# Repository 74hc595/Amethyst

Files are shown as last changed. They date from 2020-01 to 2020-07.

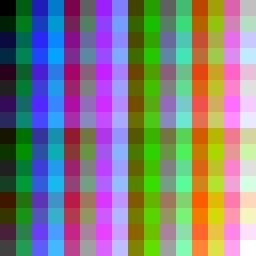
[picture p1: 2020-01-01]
palettes/8bit-preview.png

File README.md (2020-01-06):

# The Amethyst Colour Video System

https://www.youtube.com/watch?v=6GKgxBEGH1M

The Amethyst is a retro-styled "home computer" built around an Atmel ATmega1284 microcontroller.
It features composite (NTSC) video output with both high-color and high-resolution modes, mono
audio output, and a full-travel mechanical keyboard. It includes a full-featured implementation
of the powerful Forth programming language, with graphics and sound commands, debugger, and
screen editor. A single USB Type-B cable provides 5V power as well as serial communication with
a PC. Amethyst is compatible with the Optiboot (Arduino) bootloader, and new firmware may be
uploaded to it without a specialized programming device.

## Full specifications

- ATmega1284 microcontroller (8-bit) running at 14.318 MHz
- 16KB internal memory (16352 bytes available for applications)
- 4KB nonvolatile EEPROM memory
- Mechanical keyboard with Cherry MX keyswitches
- NTSC color and monochrome composite video output:

    - 256-color, 16-color, and 4-color bitmap graphics at resolutions up to 160x200 pixels
    - Monochrome bitmap graphics at resolutions up to 640x200 pixels
    - 40x25 and 80x25 monochrome text modes
    - 40x25 color text mode
    - 40x25 color tiled graphics modes
    
- Single-channel audio output (pulse wave or PWM)
- USB serial communication at speeds up to 57600 baud
- Four SPI expansion ports for peripherals, controllers, and storage devices
- Only 6 chips (ATmega1284, FT320X, 2x 74HC157, 2x 74HC166)

**TODO 1/5/20: add more detailed docs, instructions, and BOM**

## About

Amethyst is a hobby project and is not currently available for purchase in kit or built form.

Copyright 2019 Matt Sarnoff.

https://twitter.com/txsector

http://msarnoff.org

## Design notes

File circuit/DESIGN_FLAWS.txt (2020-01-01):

The Amethyst's design isn't perfect. It has several shortcomings. These
are some aspects of the design that could be improved:

The luminance levels of the video signal are dependent on the supply voltage.
Fluctuations and noise on the 5V supply can manifest as flickering changes of
brightness in the image. This is exacerbated by the fact that the Amethyst has no onboard voltage regulator; it's entirely dependent on the 5V USB supply
voltage.

I did try to run the system at 3.3V using the 3V3 output of the FTDI chip.
Technically, at 14.318 MHz, you're running the AVR outside its "safe operating
area." (See Figure 29-1 in the ATmega1284 datasheet.) Most of the time the
system would work fine, but writing to the internal EEPROM would cause the CPU
to lock up or restart. (It is documented in several threads on the avrfreaks
forums that EEPROM tends to fail when an AVR is overclocked.) However, this
could have also been due to excessive current draw from the FT230X/FT231X's
3.3V regulator, which is only rated to deliver 50 mA. It's possible that
everything might work fine using a dedicated 3.3V LDO.

No fuse or reverse voltage protection on VUSB. Needs better filtering too,
probably.

Analog video and audio output stages are garbage. My focus was on minimizing
part count instead of picture quality. I'm sure there's a lot of room for
improvement here but I'm not much of an analog guy.

No PAL support. I don't think artifact color works with PAL anyway. Your modern
TV or capture device can probably decode NTSC, though.

Derive the maximum video signal amplitude from the AVR's 2.56V/1.1V analog
voltage reference at the AREF pin. Along with some 1% resistors, this might
eliminate the need for the two trimpots VR1 and VR2.

The ortholinear keyboard layout and lack of a spacebar take a while to get
used to. This was done to minimize board real estate. Sorry if it's not your
thing.

A major drawback: the video signal is generated in software. The AVR has
no DMA, which means the CPU needs to be stolen away to bitbang the image out
to the shift registers during the active video portion of the frame. This only
leaves about 25% of each frame for updating your program's logic. If you
wanted to get crazy, you could probably build a dual-processor system. You
could probably even have two AVRs sharing access to an external SRAM chip. You
could use a smaller AVR as a 6845 CRT controller--it would only be responsible
for VRAM address generation, and wouldn't need to be connected to the data
lines. Or you could use another '1284 as a video coprocessor to accelerate
blitting and line drawing operations.

The biggest drawback: the AVR can't run native code from SRAM. If you don't
want to use the Forth bytecode interpreter, loading a new native application
requires reprogramming the flash memory, which only has a finite number of
write cycles. An Arm would be better suited, but then (a) it wouldn't be
"8-bit," and (b) it wouldn't be constructible on a breadboard. (Rest in peace,
LPC1114FN28.)

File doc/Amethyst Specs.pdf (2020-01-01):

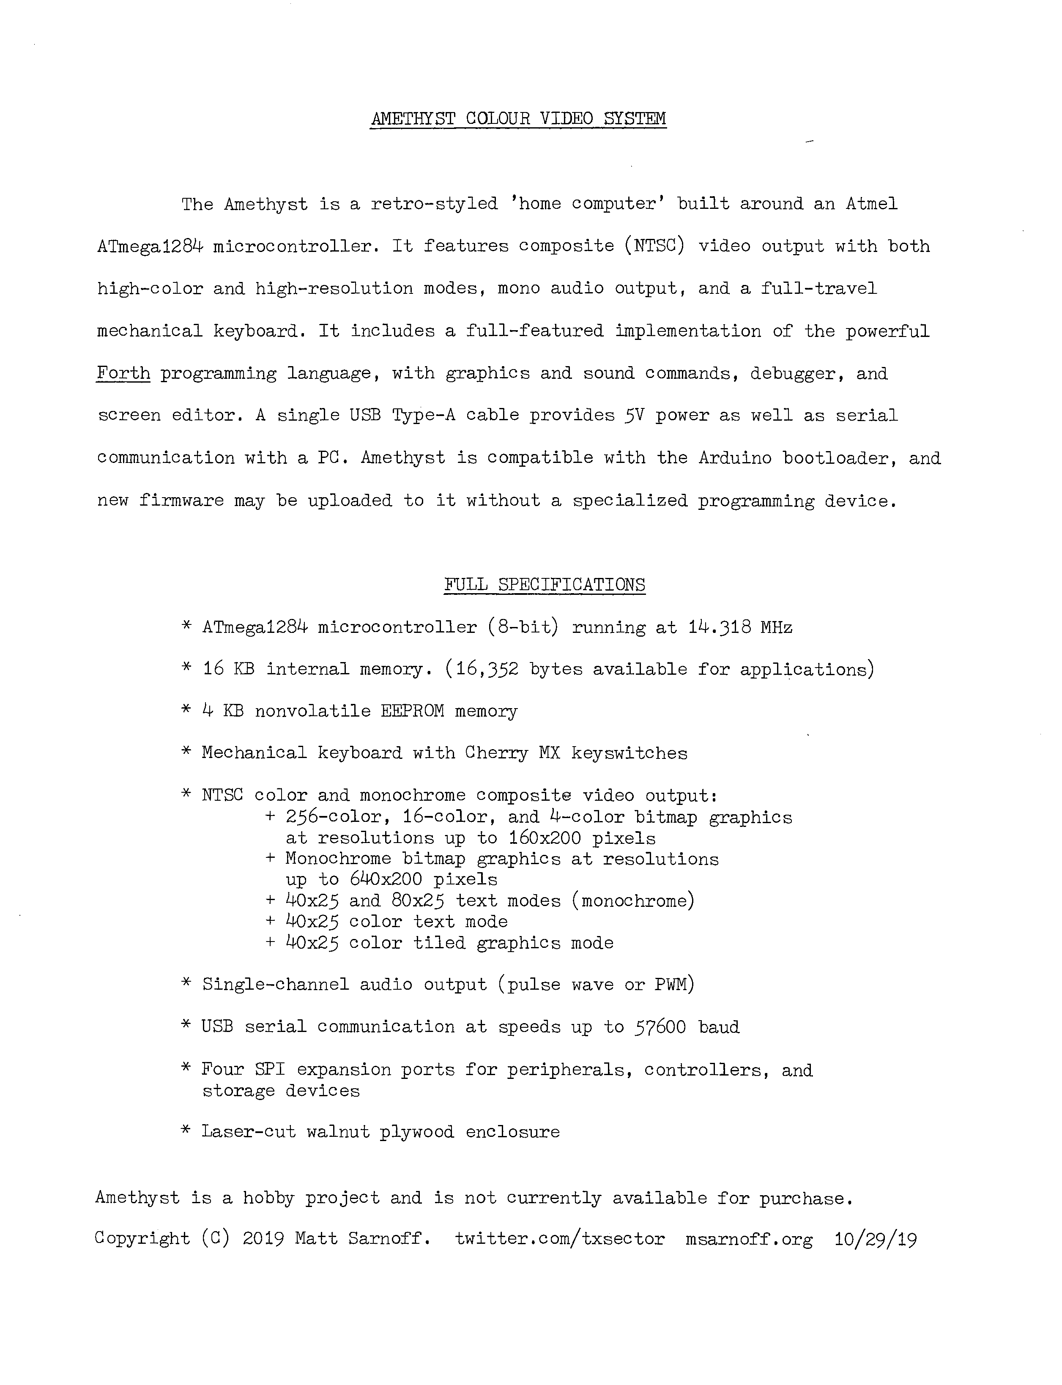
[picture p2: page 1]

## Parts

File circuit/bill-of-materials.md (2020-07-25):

## Amethyst Bill of Materials

| Reference | Qty | Description | Vendor link |
| --- | --- | --- | --- |
| C1-C2 | 2 | Capacitor, MLCC, 0603, 18pF, 50V, NPO, 5% | [Mouser](https://www.mouser.com/ProductDetail/603-CC603JRNPO9BN180) |
| C3-C5, C7-C11, C14-C16 | 10  | Capacitor, MLCC, 0603, 0.1uF, 10V, X7R, 5% | [Mouser](https://www.mouser.com/ProductDetail/77-VJ0603Y104JXQCBC) |
| C6 | 1 | Capacitor, electrolytic, through-hole, 10uF, 25V | Generic [(Amazon)](https://www.amazon.com/REXQualis-Electrolytic-Capacitor-Assortment-0-1uF-1000uF/dp/B081PT78Y5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) |
| C12-C13 | 2 | Capacitor, MLCC, 0603, 47pF, 100V, C0G, 5% | [Mouser](https://www.mouser.com/ProductDetail/KEMET/C0603C470J1GACTU?qs=sGAEpiMZZMvsSlwiRhF8qnEcMcxHm24QR9VWEEhdETo%3D) |
| D1-D47 | 47  | Diode, SMD, BAS16HT1G | [Mouser](https://www.mouser.com/ProductDetail/863-BAS16HT1G) |
| J1 | 1 | Connector, USB-B, right-angle, through-hole | [Jameco](https://www.jameco.com/shop/ProductDisplay?catalogId=10001&langId=-1&storeId=10001&productId=2096245) |
| J2 | 1 | Pin header, 0.1" pitch, straight, through hole, 2x3 | Generic [(Amazon)](https://www.amazon.com/Frienda-Break-Away-Connector-Compatible-Raspberry/dp/B083DYVWDN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) |
| J3 | 1 | Connector, RCA, female, right-angle, through-hole, yellow | [Jameco](https://www.jameco.com/z/KY-006-1-Y--Connector-RCA-Female-2-Position-Right-Angle-Thru-Hole-2-Terminal_220564.html) |
| J4 | 1 | Connector, RCA, female, right-angle, through-hole, white  | [Jameco](https://www.jameco.com/z/KY-006-1-Y--Connector-RCA-Female-2-Position-Right-Angle-Thru-Hole-2-Terminal_220564.html) |
| J5-J6 | 2 | Pin socket, 0.1" pitch, right-angle, through-hole, 1x6 | Generic [(Amazon)](https://www.amazon.com/Right-Female-Header-2-54mm-Connector/dp/B00R1M3JRQ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) |
| J7 | 1 | Pin socket, 0.1" pitch, right-angle, through-hole, 1x4 | Generic [(Amazon)](https://www.amazon.com/Right-Female-Header-2-54mm-Connector/dp/B00R1M3JRQ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) |
| J8-J9 | 2 | Connector, RJ-11, right-angle, through-hole, 6P6C | [Amazon](https://www.amazon.com/gp/product/B00LUT5VA4/ref=ppx_yo_dt_b_search_asin_title?ie=UTF8&psc=1) |
| K1-K47 | 47  | Keyswitch, Cherry MX, PCB mount (any color) | [MechanicalKeyboards.com](https://mechanicalkeyboards.com/shop/index.php?l=product_detail&p=1027) |
| (K1-K47) | 1 | DSA "Beyond" keycap set | [PimpMyKeyboard.com](https://pimpmykeyboard.com/dsa-beyond-keyset-sublimated/) |
| LED1 | 1 | LED, SMD, 1206 (any color) | Generic [(Amazon)](https://www.amazon.com/Assorted-Lighting-Electronics-Components-Emitting/dp/B01CUGAFEC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) |
| R1 | 1 | Resistor, SMD, 0603, 10k ohm, 100 mW, 5% | [Mouser](https://www.mouser.com/ProductDetail/Yageo/RC0603JR-0710KL?qs=ksOUTF%2FWcd8D6T22BJkQ7g%3D%3D) |
| R2 | 1 | Resistor, SMD, 0603, 1k ohm, 100 mW, 5% | [Mouser](https://www.mouser.com/ProductDetail/Yageo/RC0603JR-071KL?qs=%2F9ZTgpVJnN7bctK4R%2FDEoA%3D%3D) |
| R3-R4 | 2 | Resistor, SMD, 0603, 27 ohm, 100 mW, 1% | [Mouser](https://www.mouser.com/ProductDetail/Yageo/RC0603FR-0727RL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) |
| R5 | 1 | Resistor, SMD, 1206, 1.5k ohm*, 1/4 W, 1% | [Mouser](https://www.mouser.com/ProductDetail/Yageo/RT1206FRE071K5L?qs=8cPjvKtxWv7kOFMaeXZkoQ%3D%3D) |
| SW1 | 1 | Push switch, FSMSM | [Mouser](https://www.mouser.com/ProductDetail/TE-Connectivity-Alcoswitch/FSMSM?qs=UhRTNahLC3yPLf3YjzjKAA%3D%3D) |
| SW2 | 1 | Slide switch, SMD, PCM12 | [Amazon](https://www.amazon.com/gp/product/B01GFFGA4I/ref=ppx_yo_dt_b_search_asin_title?ie=UTF8&psc=1), [Mouser](https://www.mouser.com/ProductDetail/CK/PCM12SMTR?qs=mfFuHy8STfL3qrPSfCHA7w%3D%3D) |
| U1 | 1 | IC, ATmega1284P-PU, DIP-40 | [Mouser](https://www.mouser.com/ProductDetail/Microchip-Technology-Atmel/ATMEGA1284P-PU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) |
| (U1) | 1 | IC socket, 40 pin DIP | Generic [(Amazon)](https://www.amazon.com/Glarks-122Pcs-adaptadores-soldadura-40-pines/dp/B01GOLSUAU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) |
| U2-U3 | 2 | IC, 74HC157, DIP-16 | [Mouser](https://www.mouser.com/ProductDetail/Texas-Instruments/SN74HC157N?qs=UGVLDq%2F29uh%252BlECfoxfSbw%3D%3D) |
| U4-U5 | 2 | IC, 74HC166, DIP-16 | [Mouser](https://www.mouser.com/ProductDetail/595-SN74HC166N) |
| (U2-U5) | 4 | IC socket, 16 pin DIP | Generic [(Amazon)](https://www.amazon.com/Glarks-122Pcs-adaptadores-soldadura-40-pines/dp/B01GOLSUAU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) |
| U6 | 1 | IC, FT230XS-R, SSOP-16 | [Mouser](https://www.mouser.com/ProductDetail/895-FT230XS-R) |
| VR1-VR2 | 2 | Potentiometer, 2k ohm, Bourns 3296W (or clone) | [Amazon](https://www.amazon.com/gp/product/B0711MB4TL/ref=ppx_yo_dt_b_search_asin_title?ie=UTF8&psc=1) |
| VR3 | 1 | Potentiometer, 10k ohm, Bourns 3296W (or clone) | [Amazon](https://www.amazon.com/gp/product/B0711MB4TL/ref=ppx_yo_dt_b_search_asin_title?ie=UTF8&psc=1) |
| Y1 | 1 | Crystal, HC-49/US, 14.31818MHz | [Mouser](https://www.mouser.com/ProductDetail/ABRACON/ABL-1431818MHZ-B2?qs=GgB7MJ%2FTIsS1ZuFigpgyCQ%3D%3D) |
| PCB | 1 | Amethyst printed circuit board, rev 1.2 | [OSHPark](https://oshpark.com/shared_projects/2bLMCsl2), [JLCPCB](https://cart.jlcpcb.com/quote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) |

_*_ R5: actual value will depend on color of LED1 and desired brightness.

You will also need an AVR programmer to burn the bootloader to the ATmega1284P (U1). The [AVRISP mkII](https://www.microchip.com/DevelopmentTools/ProductDetails/PartNO/ATAVRISP2) is no longer manufatured,
but there are other options:

- [SparkFun Pocket AVR Programmer](https://www.sparkfun.com/products/9825)
- An [Arduino](https://www.arduino.cc/en/Tutorial/ArduinoISP) can be used as an ISP programmer
- [SparkFun AVR Programmer HAT](https://www.sparkfun.com/products/14747) for Raspberry Pi
- [AVRISP mkII clones](https://www.amazon.com/official-Programmer-Compatible-Supports-interface/dp/B07B6NHG63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) are available

Note that I have only tested burning the bootloader with an official AVRISP mkII unit, and I can't
provide specific instructions for these alternatives at this time.

Once the bootloader has been burned to the ATmega chip, the AVR programmer is no longer required.
Further programming only requires a USB-B cable.

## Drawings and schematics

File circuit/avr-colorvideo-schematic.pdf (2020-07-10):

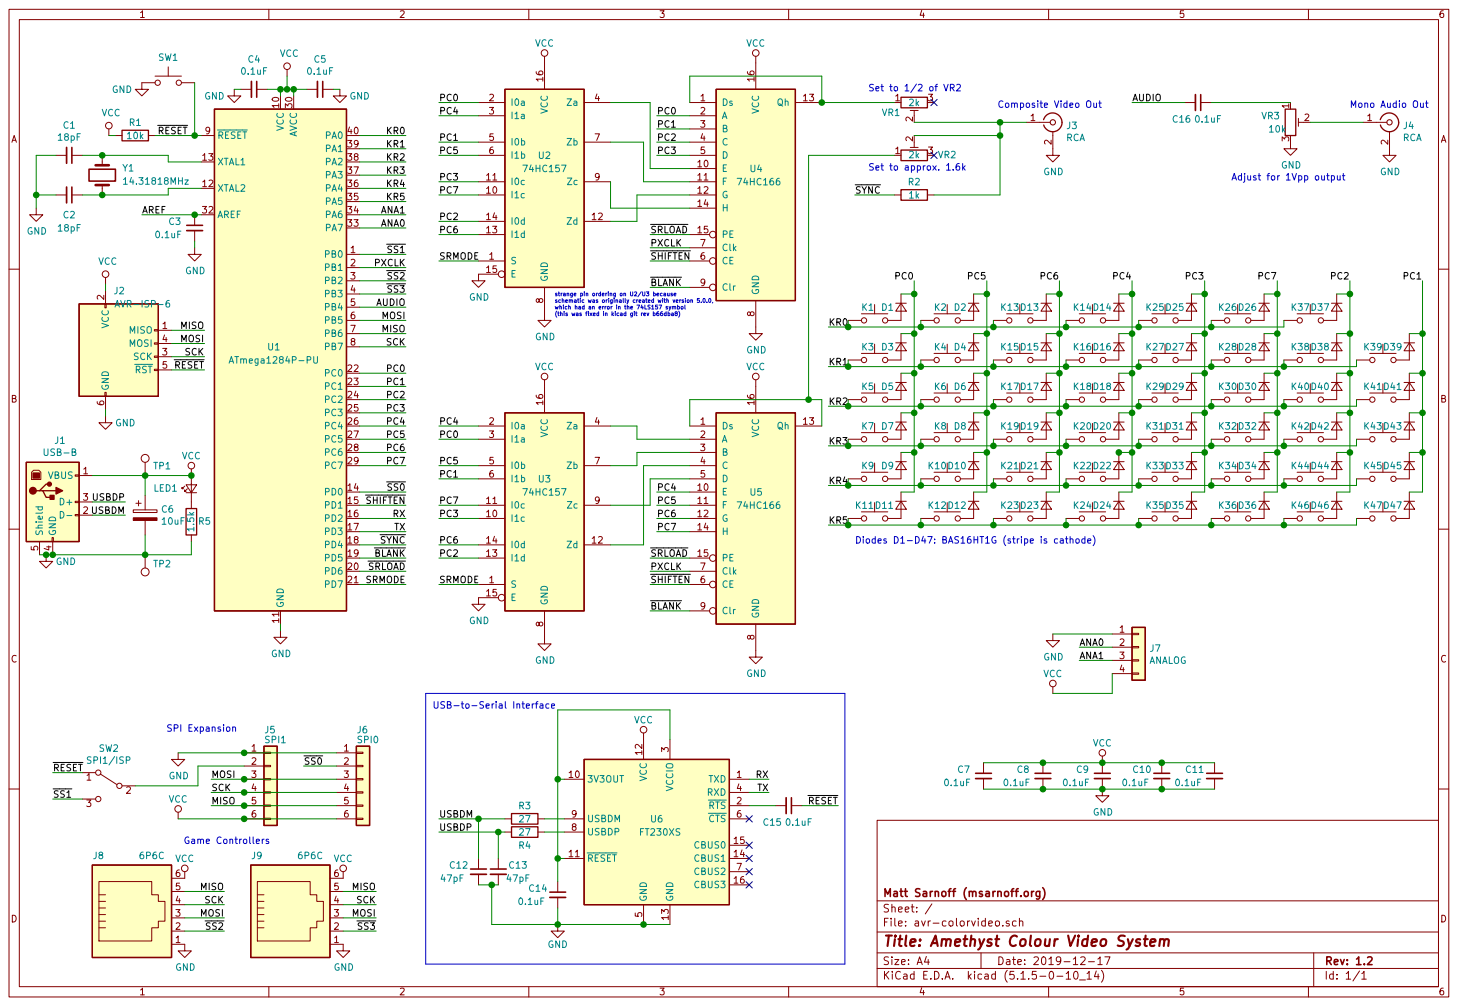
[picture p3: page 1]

2 SCK 3 MOSI 4 RST 5 GND

schematic was originally created with version 5.0.0, which had an error in the 74LS157 symbol (this was fixed in kicad git rev b66dba8) Game Controllers

strange pin ordering on U2/U3 because

File: avr-colorvideo.sch Sheet: / Matt Sarnoff (msarnoff.org) GND

Id: 1/1 Title: Amethyst Colour Video System

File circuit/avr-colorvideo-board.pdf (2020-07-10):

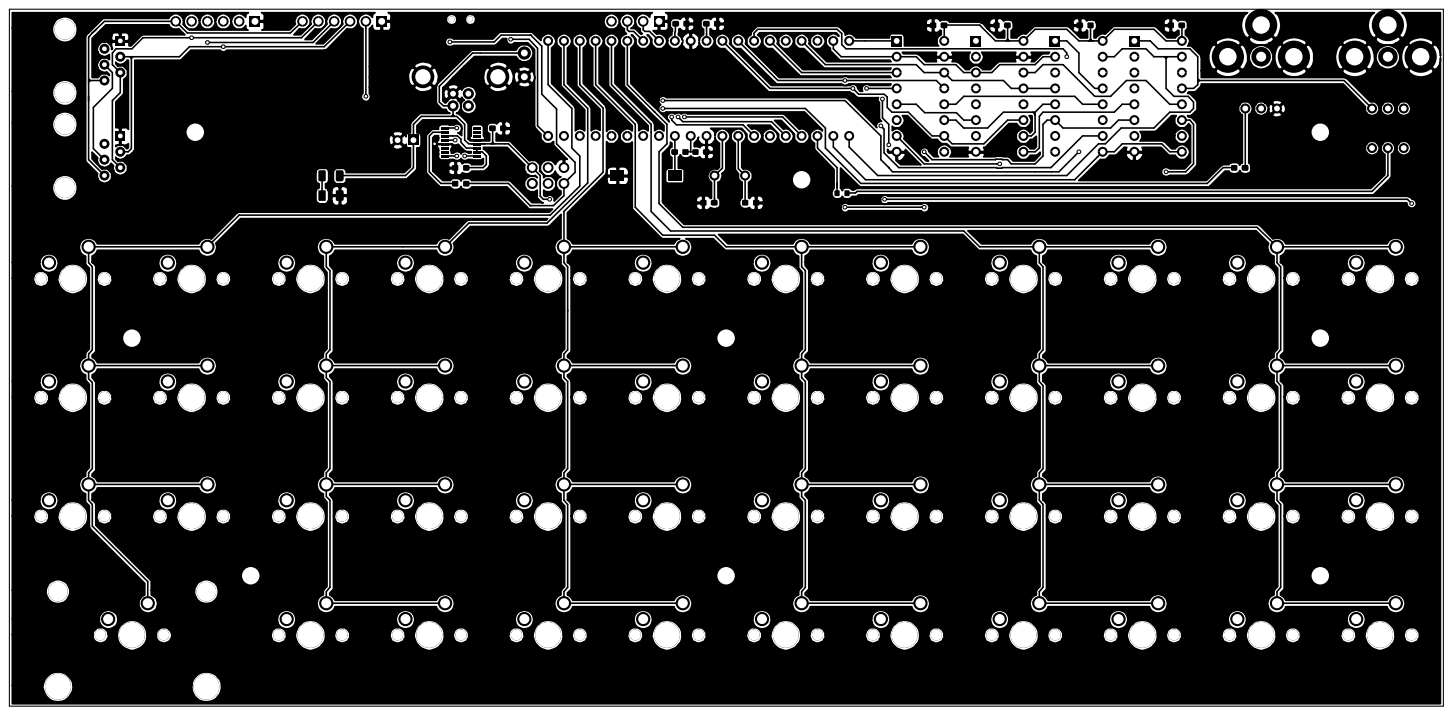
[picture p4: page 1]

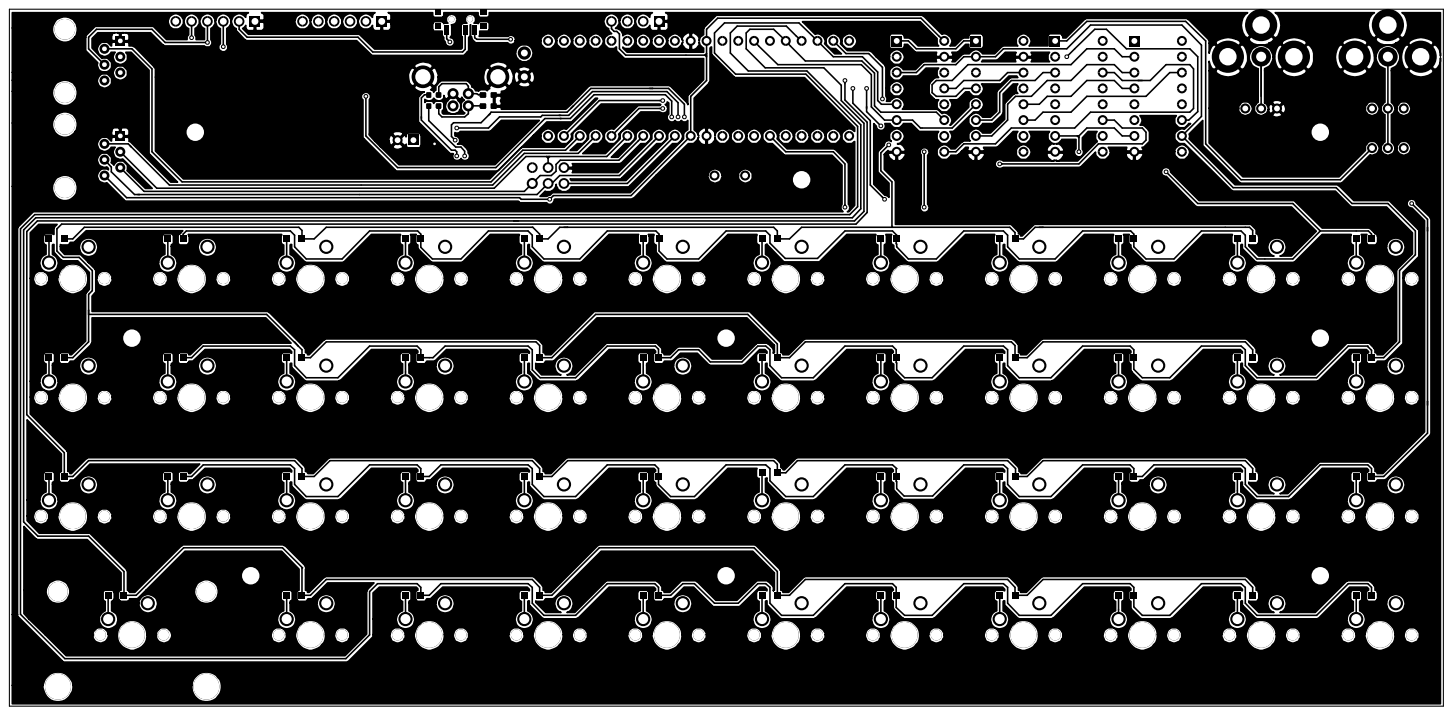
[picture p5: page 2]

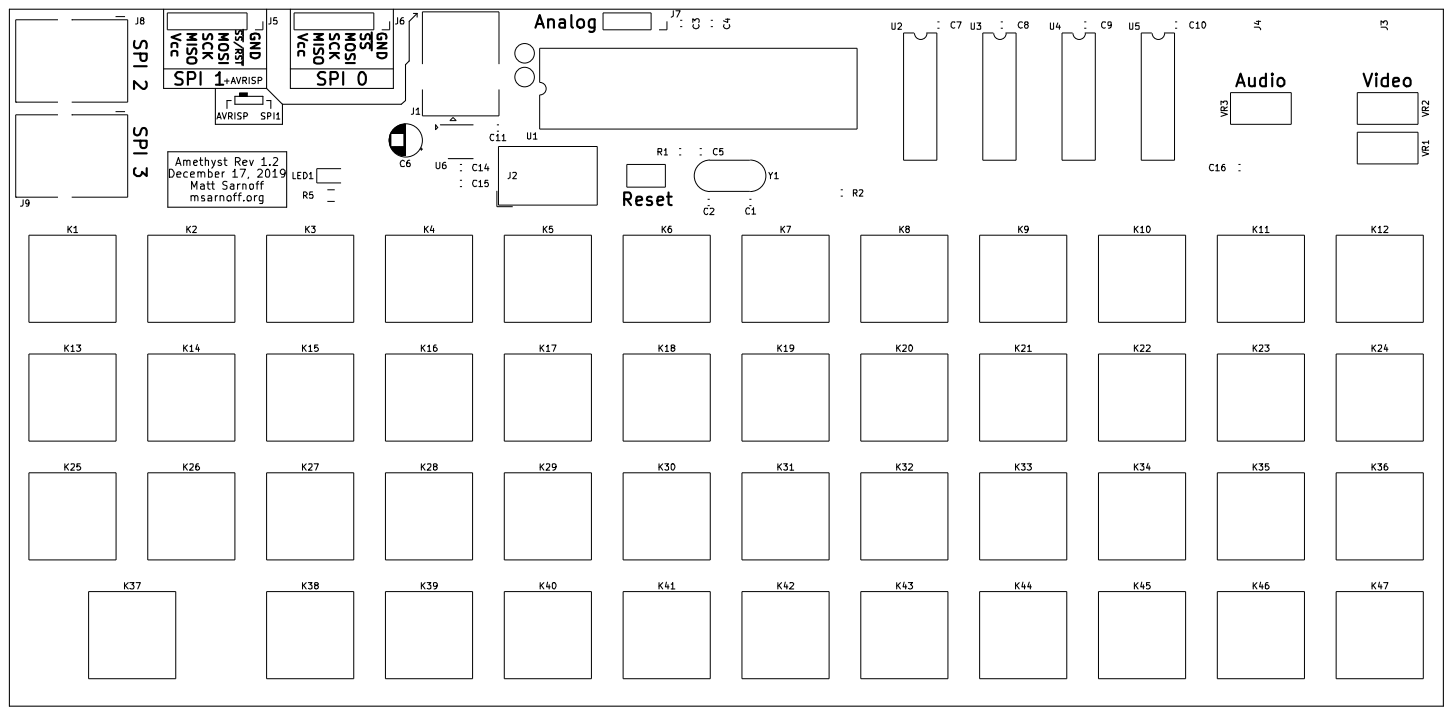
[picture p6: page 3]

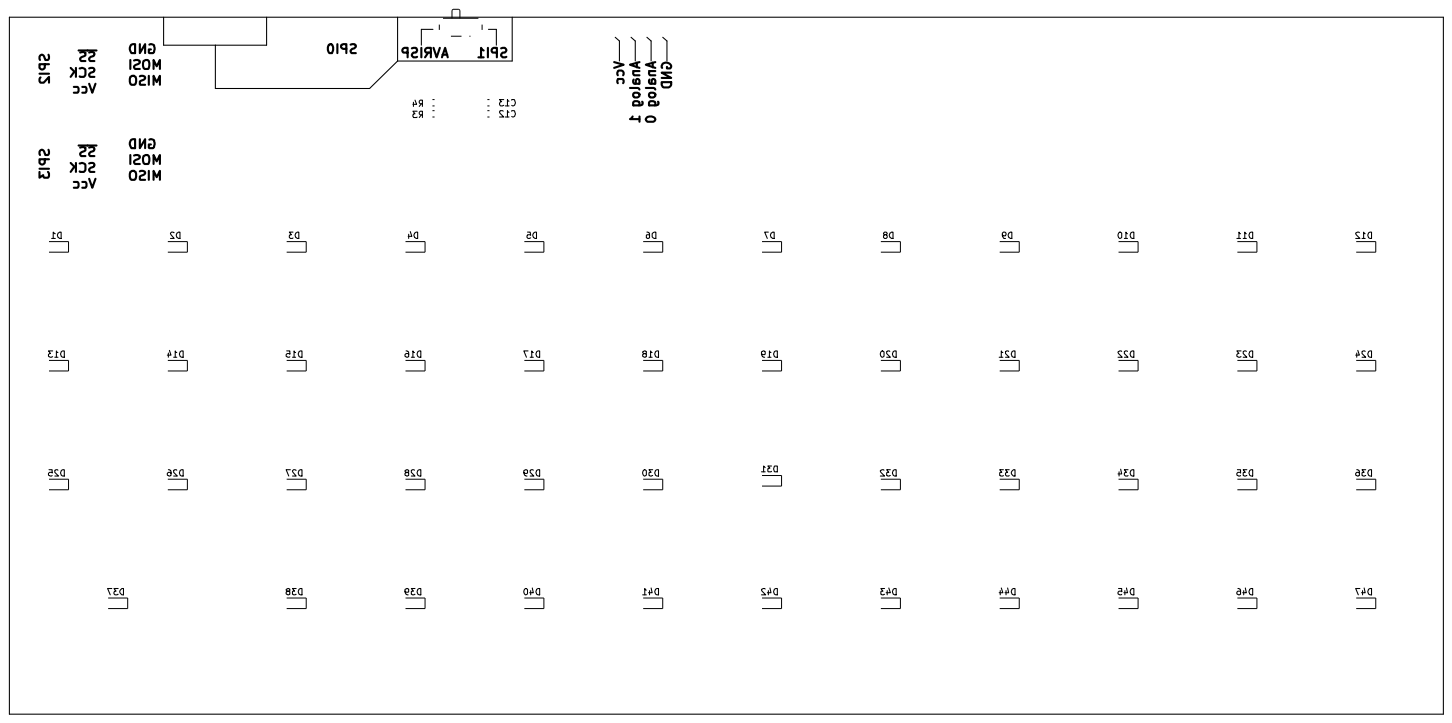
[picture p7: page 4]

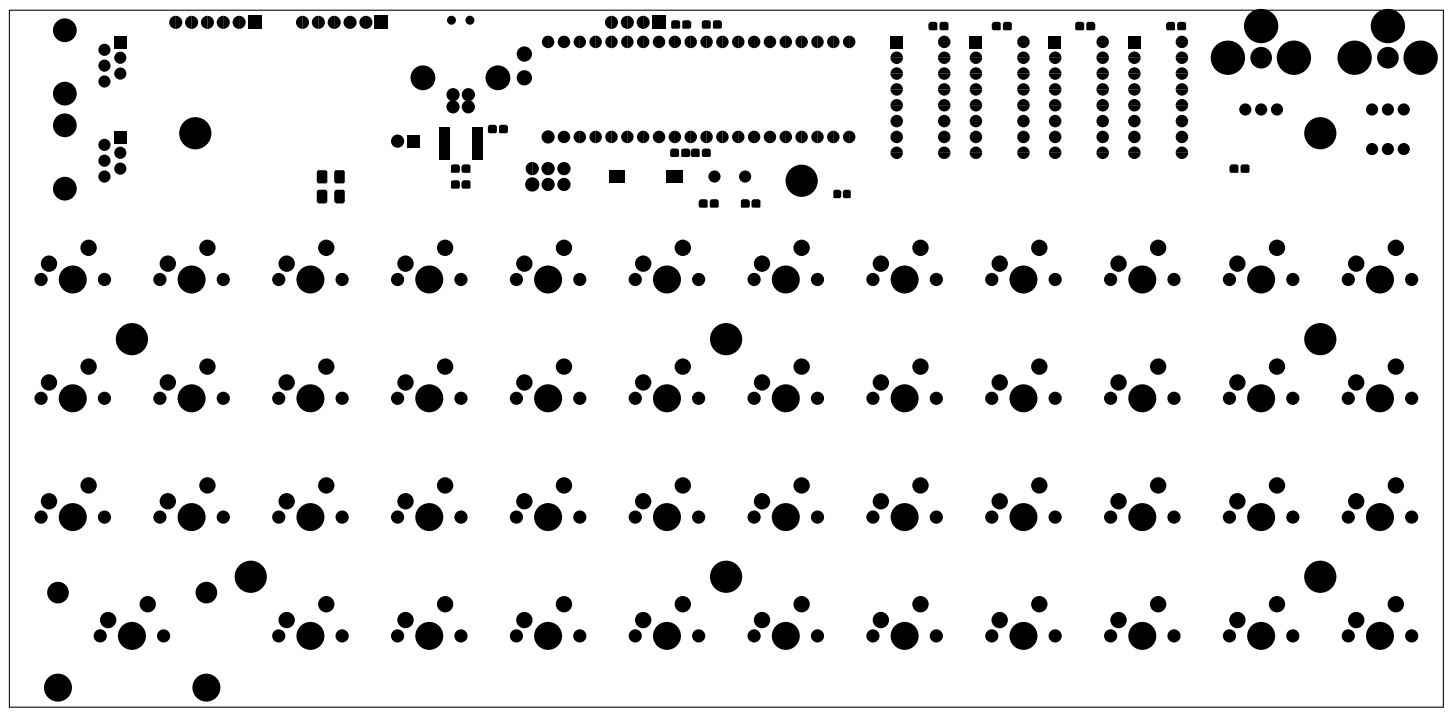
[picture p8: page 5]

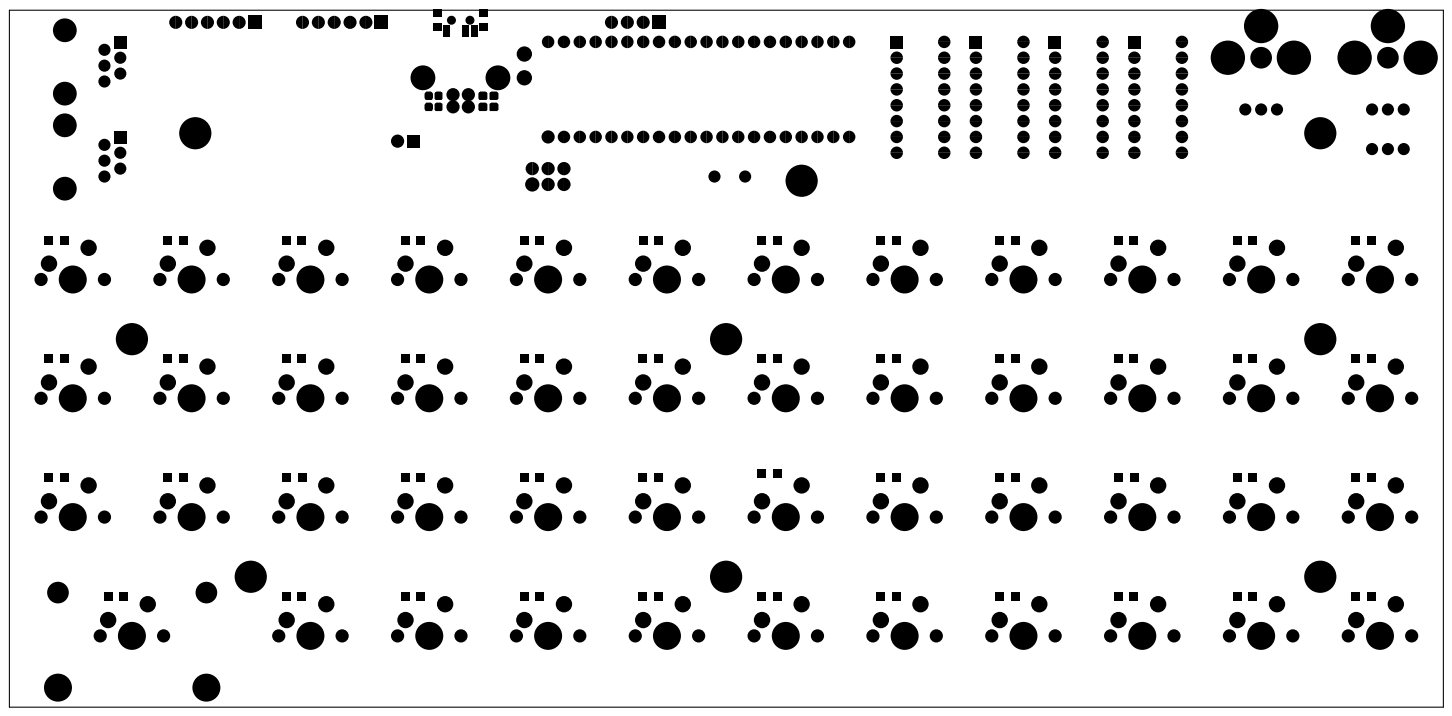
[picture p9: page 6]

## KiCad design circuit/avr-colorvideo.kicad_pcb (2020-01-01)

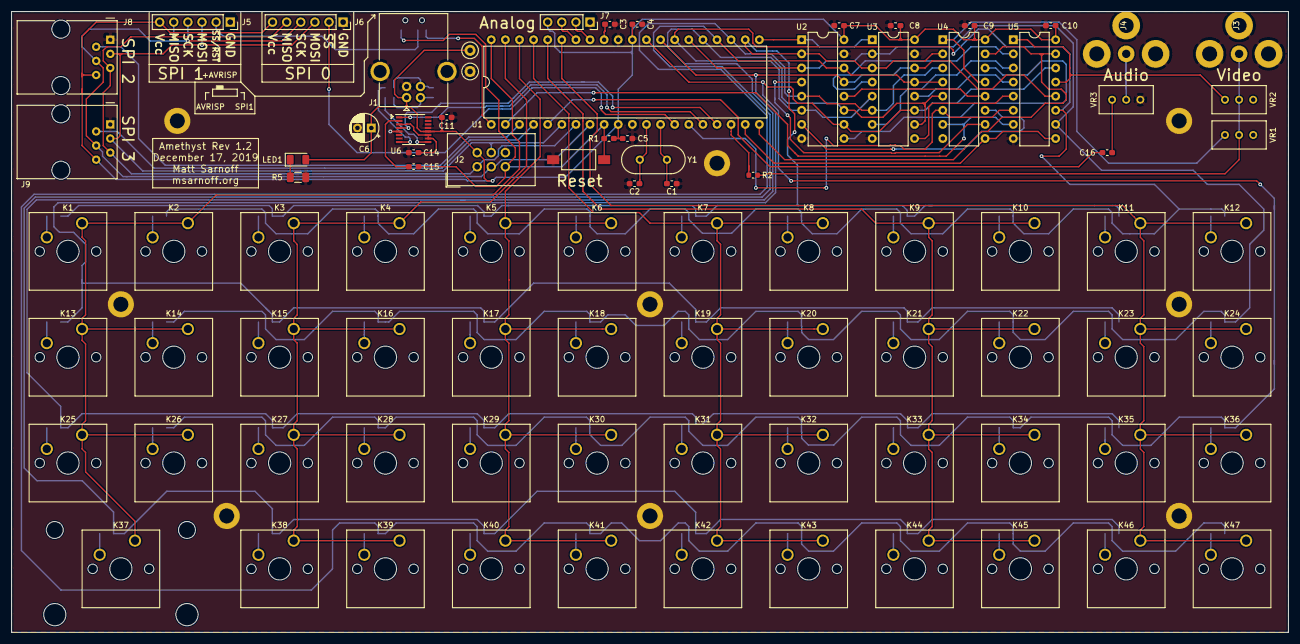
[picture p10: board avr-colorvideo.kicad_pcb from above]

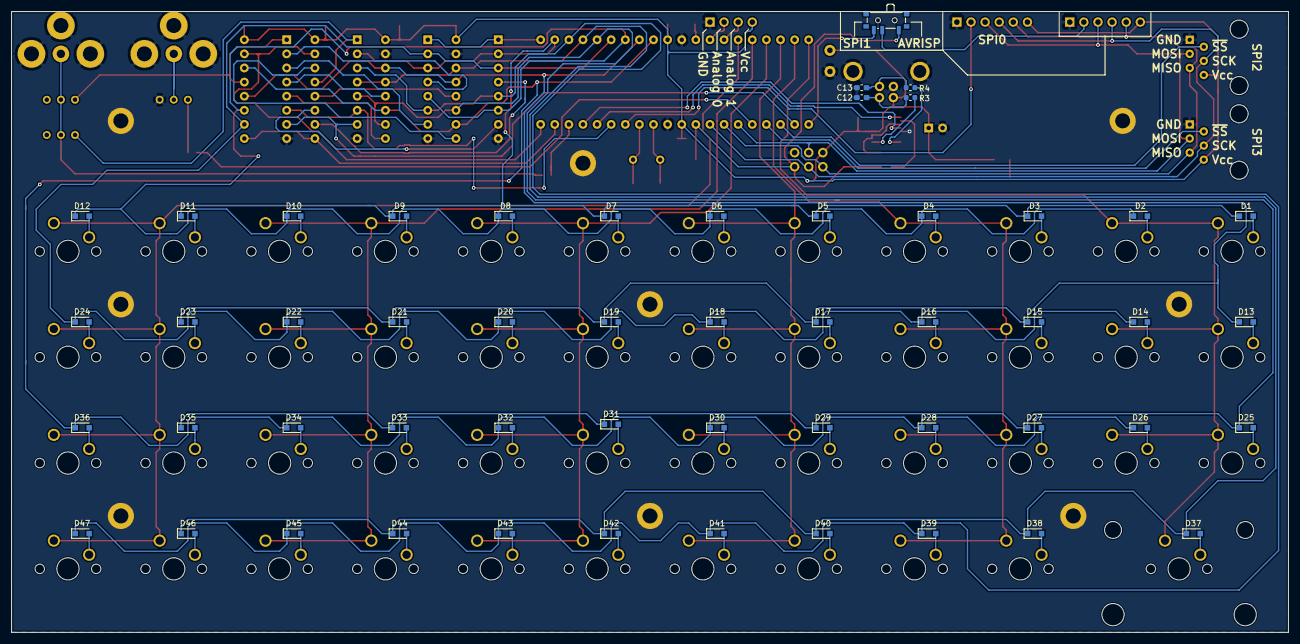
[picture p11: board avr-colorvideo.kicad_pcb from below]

Board: 2 copper layers, 229.9 x 111.8 mm, 139 parts (52 on the bottom side), 106 nets.

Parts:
C1, C2: 18pF; C_0603_1608Metric_Pad1.05x0.95mm_HandSolder
C3, C4, C5, C7, C8, C9, C10, C11, C14, C15, C16: 0.1uF; C_0603_1608Metric_Pad1.05x0.95mm_HandSolder
C6: 10uF; CP_Radial_D5.0mm_P2.50mm
C12, C13: 47pF; C_0603_1608Metric_Pad1.05x0.95mm_HandSolder
D1, D2, D3, D4, D5, D6, D7, D8, D9, D10, D11, D12, D13, D14, D15, D16, D17, D18, D19, D20, D21, D22, D23, D24, D25, D26, D27, D28, D29, D30, D31, D32, D33, D34, D35, D36, D37, D38, D39, D40, D41, D42, D43, D44, D45, D46, D47: D_Small; D_SOD-323_HandSoldering
J1: USB-B; USB_B_OST_USB-B1HSxx_Horizontal
J2: AVR-ISP-6; IDC-Header_2x03_P2.54mm_Vertical
J3, J4: RCA; RCA_Jack_Jameco_KY-006-1
J5: SPI1; PinSocket_1x06_P2.54mm_Vertical
J6: SPI0; PinSocket_1x06_P2.54mm_Vertical
J7: ANALOG; PinSocket_1x04_P2.54mm_Vertical
J8, J9: 6P6C; RJ12_Amphenol_54601
K1, K2, K3, K4, K5, K6, K7, K8, K9, K10, K11, K12, K13, K14, K15, K16, K17, K18, K19, K20, K21, K22, K23, K24, K25, K26, K27, K28, K29, K30, K31, K32, K33, K34, K35, K36, K38, K39, K40, K41, K42, K43: SW_Push; SW_Cherry_MX1A_1.00u_PCB
K37: SW_Push; SW_Cherry_MX_2.00u_PCB
K44, K45, K46, K47: SW_Push; SW_Cherry_MX_1.00u_PCB
LED1: LED_Small; LED_1206_3216Metric
R1: 10k; R_0603_1608Metric_Pad1.05x0.95mm_HandSolder
R2: 1k; R_0603_1608Metric
R3, R4: 27; R_0603_1608Metric
R5: 1.5k; R_1206_3216Metric
SW1: SW_Push; SW_SPST_FSMSM
SW2: SPI1/ISP; SW_SPDT_PCM12
TP1, TP2: TestPoint; TestPoint_Loop_D1.80mm_Drill1.0mm_Beaded
U1: ATmega1284P-PU; DIP-40_W15.24mm
U2, U3: 74HC157; DIP-16_W7.62mm
U4, U5: 74HC166; DIP-16_W7.62mm
U6: FT230XS; SSOP-16_3.9x4.9mm_P0.635mm
VR1, VR2: 2k; Potentiometer_Bourns_3296W_Vertical
VR3: 10k; Potentiometer_Bourns_3296W_Vertical
Y1: 14.31818MHz; Crystal_HC49-4H_Vertical

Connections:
/ANA0: J7.2, U1.33
/ANA1: J7.3, U1.34
/AREF: C3.1, U1.32
/AUDIO: C16.2, U1.5
/KR0: K1.1, K2.1, K13.1, K14.1, K25.1, K26.1, K37.1, U1.40
/KR1: K3.1, K4.1, K15.1, K16.1, K27.1, K28.1, K38.1, K39.1, U1.39
/KR2: K5.1, K6.1, K17.1, K18.1, K29.1, K30.1, K40.1, K41.1, U1.38
/KR3: K7.1, K8.1, K19.1, K20.1, K31.1, K32.1, K42.1, K43.1, U1.37
/KR4: K9.1, K10.1, K21.1, K22.1, K33.1, K34.1, K44.1, K45.1, U1.36
/KR5: K11.1, K12.1, K23.1, K24.1, K35.1, K36.1, K46.1, K47.1, U1.35
/MISO: J2.1, J5.5, J6.5, J8.5, J9.5, U1.7
/MOSI: J2.4, J5.3, J6.3, J8.3, J9.3, U1.6
/PC0: D1.1, D3.1, D5.1, D7.1, D9.1, D11.1, U1.22, U2.2, U3.3, U4.2
/PC1: D39.1, D41.1, D43.1, D45.1, D47.1, U1.23, U2.5, U3.6, U4.3
/PC2: D37.1, D38.1, D40.1, D42.1, D44.1, D46.1, U1.24, U2.14, U3.13, U4.4
/PC3: D25.1, D27.1, D29.1, D31.1, D33.1, D35.1, U1.25, U2.11, U3.10, U4.5
/PC4: D14.1, D16.1, D18.1, D20.1, D22.1, D24.1, U1.26, U2.3, U3.2, U5.10
/PC5: D2.1, D4.1, D6.1, D8.1, D10.1, D12.1, U1.27, U2.6, U3.5, U5.11
/PC6: D13.1, D15.1, D17.1, D19.1, D21.1, D23.1, U1.28, U2.13, U3.14, U5.12
/PC7: D26.1, D28.1, D30.1, D32.1, D34.1, D36.1, U1.29, U2.10, U3.11, U5.14
/PXCLK: U1.2, U4.7, U5.7
/RX: U1.16, U6.1
/SCK: J2.3, J5.4, J6.4, J8.4, J9.4, U1.8
/SRMODE: U1.21, U2.1, U3.1
/TX: U1.17, U6.4
/USBDM: C12.1, J1.2, R3.2
/USBDP: C13.1, J1.3, R4.2
/~BLANK: U1.19, U4.9, U5.9
/~RESET: C15.1, J2.5, R1.1, SW1.2, SW2.1, U1.9
/~SHIFTEN: U1.15, U4.6, U5.6
/~SRLOAD: U1.20, U4.15, U5.15
/~SS0: J6.2, U1.14
/~SS1: SW2.3, U1.1
/~SS2: J8.2, U1.3
/~SS3: J9.2, U1.4
/~SYNC: R2.2, U1.18
GND: C1.2, C2.2, C3.2, C4.2, C5.1, C6.2, C7.2, C8.2, C9.2, C10.2, C11.2, C12.2, C13.2, C14.2, J1.4, J1.5, J2.6, J3.2, J4.2, J5.1, J6.1, J7.1, J8.1, J9.1, R5.1, SW1.1, TP2.1, U1.11, U1.31, U2.8, U2.15, U3.8, U3.15, U4.8, U5.8, U6.5, U6.13, VR3.3
unnamed: C1.1, U1.13, Y1.2
unnamed: C2.1, U1.12, Y1.1
unnamed: C14.1, U6.3, U6.10, U6.11
unnamed: C15.2, U6.2
unnamed: C16.1, VR3.1
unnamed: D1.2, K1.2
unnamed: D2.2, K2.2
unnamed: D3.2, K3.2
unnamed: D4.2, K4.2
unnamed: D5.2, K5.2
unnamed: D6.2, K6.2
unnamed: D7.2, K7.2
unnamed: D8.2, K8.2
unnamed: D9.2, K9.2
unnamed: D10.2, K10.2
unnamed: D11.2, K11.2
unnamed: D12.2, K12.2
unnamed: D13.2, K13.2
unnamed: D14.2, K14.2
unnamed: D15.2, K15.2
unnamed: D16.2, K16.2
unnamed: D17.2, K17.2
unnamed: D18.2, K18.2
unnamed: D19.2, K19.2
unnamed: D20.2, K20.2
unnamed: D21.2, K21.2
unnamed: D22.2, K22.2
unnamed: D23.2, K23.2
unnamed: D24.2, K24.2
unnamed: D25.2, K25.2
unnamed: D26.2, K26.2
unnamed: D27.2, K27.2
unnamed: D28.2, K28.2
unnamed: D29.2, K29.2
unnamed: D30.2, K30.2
unnamed: D31.2, K31.2
unnamed: D32.2, K32.2
unnamed: D33.2, K33.2
unnamed: D34.2, K34.2
unnamed: D35.2, K35.2
unnamed: D36.2, K36.2
unnamed: D37.2, K37.2
unnamed: D38.2, K38.2
unnamed: D39.2, K39.2
unnamed: D40.2, K40.2
unnamed: D41.2, K41.2
unnamed: D42.2, K42.2
unnamed: D43.2, K43.2
unnamed: D44.2, K44.2
unnamed: D45.2, K45.2
unnamed: D46.2, K46.2
unnamed: D47.2, K47.2
unnamed: J3.1, R2.1, VR1.2, VR2.2
unnamed: J4.1, VR3.2
unnamed: J5.2, SW2.2
unnamed: LED1.1, R5.2
unnamed: R3.1, U6.9
unnamed: R4.1, U6.8
unnamed: U2.4, U4.10
unnamed: U2.7, U4.11
unnamed: U2.9, U4.14
unnamed: U2.12, U4.12
unnamed: U3.4, U5.2
unnamed: U3.7, U5.3
unnamed: U3.9, U5.5
unnamed: U3.12, U5.4
unnamed: U4.1, U4.13, VR1.1
unnamed: U5.1, U5.13, VR2.1
VCC: C4.1, C5.2, C6.1, C7.1, C8.1, C9.1, C10.1, C11.1, J1.1, J2.2, J5.6, J6.6, J7.4, J8.6, J9.6, LED1.2, R1.2, TP1.1, U1.10, U1.30, U2.16, U3.16, U4.16, U5.16, U6.12

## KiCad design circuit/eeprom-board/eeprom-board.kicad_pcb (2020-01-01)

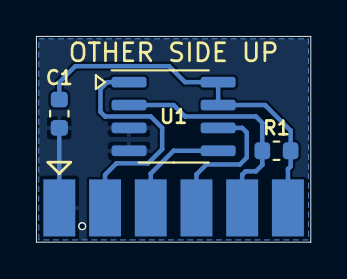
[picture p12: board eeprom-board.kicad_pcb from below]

Board: 2 copper layers, 15.2 x 11.4 mm, 4 parts (4 on the bottom side), 6 nets.

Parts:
C1: 0.1uF; C_0603_1608Metric
J1: Conn_01x06; Conn_1x06_P2.54mm_Horizontal_SMD
R1: 1k; R_0603_1608Metric
U1: CAT250xxx; SOIC-8_3.9x4.9mm_P1.27mm

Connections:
/MISO: J1.5, R1.2, U1.2
/MOSI: J1.3, U1.5
/SCK: J1.4, U1.6
/~SS: J1.2, U1.1
GND: C1.2, J1.1, U1.3, U1.4
VCC: C1.1, J1.6, R1.1, U1.7, U1.8

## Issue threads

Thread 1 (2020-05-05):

Footprints missing

bastetfurry, 2020-05-05:
The circuit is missing two footprint files:

```
Errors were encountered loading footprints:
Footprint library path "/home/bastetfurry/projekte/Amethyst/circuit/avr-isp-6.pretty" does not exist
Footprint library path "/home/bastetfurry/projekte/Amethyst/circuit/6-pin-smd.pretty" does not exist
```

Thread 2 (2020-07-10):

Circuit Schematic as pictures

vogt31337, 2020-07-10:
Hi,

I like your project. But can you export your schematic and board as pictures?
Will be much easier to view.

BR

74hc595, 2020-07-10:
Hi! I uploaded PDFs of the schematic and the board layers. Thanks for your suggestion!

Closed 2020-07-10.

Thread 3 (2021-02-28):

other CPU ?

ojej, 2021-02-28:
Is possible creating replacable cpu?
for example https://tomu.im/qomu.html
or https://hackaday.io/project/162876-lion-fpga-cpucomputer
or raspberry pi pico 2040 ?
simple add space and connect to keyboard, power and meybe small screen like https://www.clockworkpi.com/devterm

Many users need only editor and communication for world (USB flash disc or SD card or ethernet or wifi or rs232 ;) )

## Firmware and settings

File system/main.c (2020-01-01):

#include "app.h"
#include <avr/wdt.h>

#ifdef STARTUP_APP
#define STARTUP_APP_DEF PASTE_(APP_DEF_,STARTUP_APP)
#else
#error No STARTUP_APP defined
#endif

extern const struct app_def STARTUP_APP_DEF;

/* for simavr */
#include "avr_mcu_section.h"
AVR_MCU(F_CPU, "atmega1284");

/* Disable watchdog timer early in startup, so soft-resets don't lock the AVR */
/* (see avr-libc FAQ) */
void wdt_init(void) __attribute__((naked)) __attribute__((section(".init3")));
void wdt_init(void) {
  MCUSR = 0;
  wdt_disable();
}


int main()
{
  /* disable unused peripherals */
  PRR0 = _BV(PRTWI)|_BV(PRADC);
  ACSR = _BV(ACD);
  video_init();
  audio_init();
  spi_init();
  app_launch(&STARTUP_APP_DEF);
}

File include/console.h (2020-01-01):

#ifndef CONSOLE_H_
#define CONSOLE_H_

/* Constants for struct console offsets and sizes, */
/* allowing interoperability with assembler code. */
/* (Wish there was a way to generate these automatically, but the best I can*/
/* do is duplicate them and add _Static_assert()s to make sure they're right) */
#define offsetof_console_cx               0
#define offsetof_console_cy               1
#define offsetof_console_mleft            2
#define offsetof_console_mtop             3
#define offsetof_console_mright           4
#define offsetof_console_mbottom          5
#define offsetof_console_flags            6
#define offsetof_console_newline_pending  offsetof_console_cx
#define offsetof_console_rvs              offsetof_console_cy
#define offsetof_console_statusbar        offsetof_console_mtop
#define offsetof_console_slow             offsetof_console_mright
#define offsetof_console_split            offsetof_console_mbottom
#define offsetof_console_cursorphase      offsetof_console_flags
#define offsetof_console_color            offsetof_console_flags
#define offsetof_console_scrollok         offsetof_console_flags
#define offsetof_console_eightycols       offsetof_console_flags
#define sizeof_console                    16
#define bitmask_console_cx                0x7F
#define bitmask_console_newline_pending   0x80
#define bitmask_console_cy                0x7F
#define bitmask_console_rvs               0x80
#define bitmask_console_mtop              0x7F
#define bitmask_console_statusbar         0x80
#define bitmask_console_mright            0x7F
#define bitmask_console_slow              0x80
#define bitmask_console_mbottom           0x7F
#define bitmask_console_split             0x80
#define bitmask_console_cursorphase       0x1F
#define bitmask_console_color             0x20
#define bitmask_console_scrollok          0x40
#define bitmask_console_eightycols        0x80


#ifndef __ASSEMBLER__
#include "keys.h"
#include "videodefs.h"
#include <stdbool.h>
#include <stddef.h>
#include <stdint.h>
#include <stdnoreturn.h>
#include <avr/pgmspace.h>

#define CONSOLE_COLS  40
#define CONSOLE_ROWS  25
#define DEFAULT_FONT  NULL


struct console {
  /* Cursor position */
  union {
    struct {
      uint8_t cx:7;
      uint8_t newline_pending:1;
    };
    uint8_t cx__;
  };
  union {
    struct {
      uint8_t cy:7;
      uint8_t rvs:1; /* if 1, print with inverse video */
    };
    uint8_t cy__;
  };

  /* Scrolling region margins (and other flags) */
  uint8_t mleft;
  union {
    struct {
      uint8_t mtop:7;
      uint8_t statusbar:1; /* if 1, reserve the last row of the console for a status bar */
    };
    uint8_t mtop__;
  };
  union {
    struct {
      uint8_t mright:7;
      uint8_t slow:1; /* if 1, pause and wait for keypress before scrolling up */
    };
    uint8_t mright__;
  };
  union {
    struct {
      uint8_t mbottom:7;
      uint8_t split:1; /* if 1, adjust for split-screen mode */
    };
    uint8_t mbottom__;
  };
  /* Flags/state */
  union {
    struct {
      unsigned cursorphase:5; /* if 0, don't show cursor */
      unsigned color:1;
      unsigned scrollok:1;
      unsigned eightycols:1;
    };
    uint8_t flags__;
  };
  struct keyreader kr;
} __attribute__((packed));

_Static_assert(offsetof(struct console, cx__) == offsetof_console_cx, "");
_Static_assert(offsetof(struct console, cx__) == offsetof_console_newline_pending, "");
_Static_assert(offsetof(struct console, cy__) == offsetof_console_cy, "");
_Static_assert(offsetof(struct console, cy__) == offsetof_console_rvs, "");
_Static_assert(offsetof(struct console, mleft) == offsetof_console_mleft, "");
_Static_assert(offsetof(struct console, mtop__) == offsetof_console_mtop, "");
_Static_assert(offsetof(struct console, mtop__) == offsetof_console_statusbar, "");
_Static_assert(offsetof(struct console, mright__) == offsetof_console_mright, "");
_Static_assert(offsetof(struct console, mright__) == offsetof_console_slow, "");
_Static_assert(offsetof(struct console, mbottom__) == offsetof_console_mbottom, "");
_Static_assert(offsetof(struct console, mbottom__) == offsetof_console_split, "");
_Static_assert(offsetof(struct console, flags__) == offsetof_console_cursorphase, "");
_Static_assert(offsetof(struct console, flags__) == offsetof_console_color, "");
_Static_assert(offsetof(struct console, flags__) == offsetof_console_scrollok, "");
_Static_assert(offsetof(struct console, flags__) == offsetof_console_eightycols, "");
_Static_assert(sizeof(struct console) == sizeof_console, "");


#define MAKE_CONSOLE_MIO_HANDLERS_SC(name, storageclass) \
  storageclass void name##_mio_putc(char c)   { console_addch(&name,c); } \
  storageclass int  name##_mio_getc(char chk) { return console_getch(&name,chk); }

#define MAKE_CONSOLE_MIO_HANDLERS(name) \
  MAKE_CONSOLE_MIO_HANDLERS_SC(name, __attribute__((used)) static)

#define MAKE_CONSOLE_NO_CELLS(name,eightycol,colr) \
  static struct console name = { \
    .mright__ = (CONSOLE_COLS<<(eightycol))-1, \
    .mbottom__ = CONSOLE_ROWS-1, \
    .eightycols = eightycol, \
    .color = colr, \
    .scrollok = 1, \
    .cursorphase = 1 }; \
  MAKE_CONSOLE_MIO_HANDLERS(name)

#define MAKE_CONSOLE(name,eightycol,color) \
  MAKE_CONSOLE_NO_CELLS(name,eightycol,color) \
  static char name##_cells[CONSOLE_ROWS*(CONSOLE_COLS<<((eightycol)||(color)))] = {0}; \

#define MAKE_CONSOLE_40COL(name) MAKE_CONSOLE(name,0,0)
#define MAKE_CONSOLE_80COL(name) MAKE_CONSOLE(name,1,0)
#define MAKE_CONSOLE_COLOR(name) MAKE_CONSOLE(name,0,1)

#define MAKE_CONSOLE_40COL_NO_CELLS(name) MAKE_CONSOLE_NO_CELLS(name,0,0)
#define MAKE_CONSOLE_80COL_NO_CELLS(name) MAKE_CONSOLE_NO_CELLS(name,1,0)
#define MAKE_CONSOLE_COLOR_NO_CELLS(name) MAKE_CONSOLE_NO_CELLS(name,0,1)

#define CONSOLE_MIO_ACTIVATE(name) \
  mio_getc = name##_mio_getc; \
  mio_putc = name##_mio_putc;

#define CONSOLE_MIO_INIT(name) \
  CONSOLE_MIO_ACTIVATE(name) \
  console_init(&name, name##_cells, DEFAULT_FONT);

/* Waits for the start of a frame, and updates the console. */
void console_frame_sync_(struct console *c);
#define console_frame_sync(c) (({ console_frame_sync_(c); 1; }) || 1)

/* A callback-based approach, rather than "while (console_frame_sync(())" */
noreturn void console_main_loop(struct console *c, void (*idlefn)(void), void (*newframefn)(void));

/* Initializes the given console using the given font (which may be in ROM or
 * RAM), sets the appropriate video mode, and begins displaying the contents of
 * the cells array. Passing NULL uses the default 8x8 font in ROM.*/
void console_init(struct console *c, void *cells, TILEMAP_PTR font);

/* Clears the screen, returns the cursor to (0,0), and resets the margins
 * to the full size of the screen. */
void console_clrhome(struct console *c);

/* Clears the scrolling region, and returns the cursor to the upper left of
 * the scrolling region. */
void console_clrscroll(struct console *c);
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

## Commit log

2020-07-10 [#2] add schematic pdf
2020-07-10 fixes #2 - add image of board layers
2020-07-25 add bill of materials
